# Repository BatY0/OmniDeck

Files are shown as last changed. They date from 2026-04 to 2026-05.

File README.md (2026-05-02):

# OmniDeck: An Asymmetric IoT Puzzle Platform

## Project Summary
OmniDeck is an innovative, asymmetric cooperative IoT hardware platform designed to merge physical puzzles with digital cloud-based mechanics—creating a "Keep Talking and Nobody Explodes" style escape room experience. Acting as a "Dumb Terminal," the physical device utilizes an ESP32 to read environmental and interactive telemetry (spatial orientation, rotational vault-cracking inputs, proximity, temperature, and light intensity) and publishes this data to the Arduino IoT Cloud in real-time via WebSockets. A remote "Hacker" monitors these live feeds on a web dashboard and transmits haptic (vibration) clues and game-stage commands back to the console. The cloud platform functions as the ultimate Game Master, orchestrating a complete Sense-Think-Act cycle where the physical hardware is fully decoupled from the game logic, eventually releasing a mechanical servo-latch upon successful cooperation.

## Components List
Our project exceeds the minimum requirements (2 sensors + OLED + 1 actuator) by utilizing a comprehensive ecosystem of components:
*   **Microcontroller:** ESP32 Development Board (ESP-WROOM-32)
*   **Display:** 0.96" I2C OLED Display (128x64)
*   **Sensor 1:** MPU6050 (Accelerometer/Gyroscope)
*   **Sensor 2:** KY-040 (Rotary Encoder with Push Button)
*   **Sensor 3:** HC-SR04 (Ultrasonic Distance Sensor)
*   **Sensor 4:** DHT11 (Temperature & Humidity Sensor)
*   **Sensor 5:** 4-Pin LDR (Light Dependent Resistor Module)
*   **Actuator 1:** SG90 Micro Servo Motor
*   **Actuator 2:** Vibration Motor Module

## Wiring Table & Diagram

| Component | Component Pin | ESP32 GPIO Pin | Notes |
| :--- | :--- | :--- | :--- |
| **OLED Display** | SDA / SCL | GPIO 21 / GPIO 22 | I2C Bus (3.3V) |
| **MPU6050** | SDA / SCL | GPIO 21 / GPIO 22 | I2C Bus (3.3V) |
| **KY-040 Encoder** | CLK / DT / SW | GPIO 32 / 33 / 25 | Hardware Interrupt (3.3V) |
| **HC-SR04** | TRIG / ECHO | GPIO 5 / GPIO 18 | 5V VIN Powered |
| **DHT11** | DATA (S) | GPIO 4 | 3.3V Powered |
| **LDR Module** | A0 (Analog) | GPIO 34 | Analog Input (3.3V) |
| **SG90 Servo** | SIGNAL (Orange) | GPIO 26 | 5V VIN Powered |
| **Vibration Motor**| IN (Signal) | GPIO 27 | 3.3V Powered |

### Wiring Diagram

<p align="center">
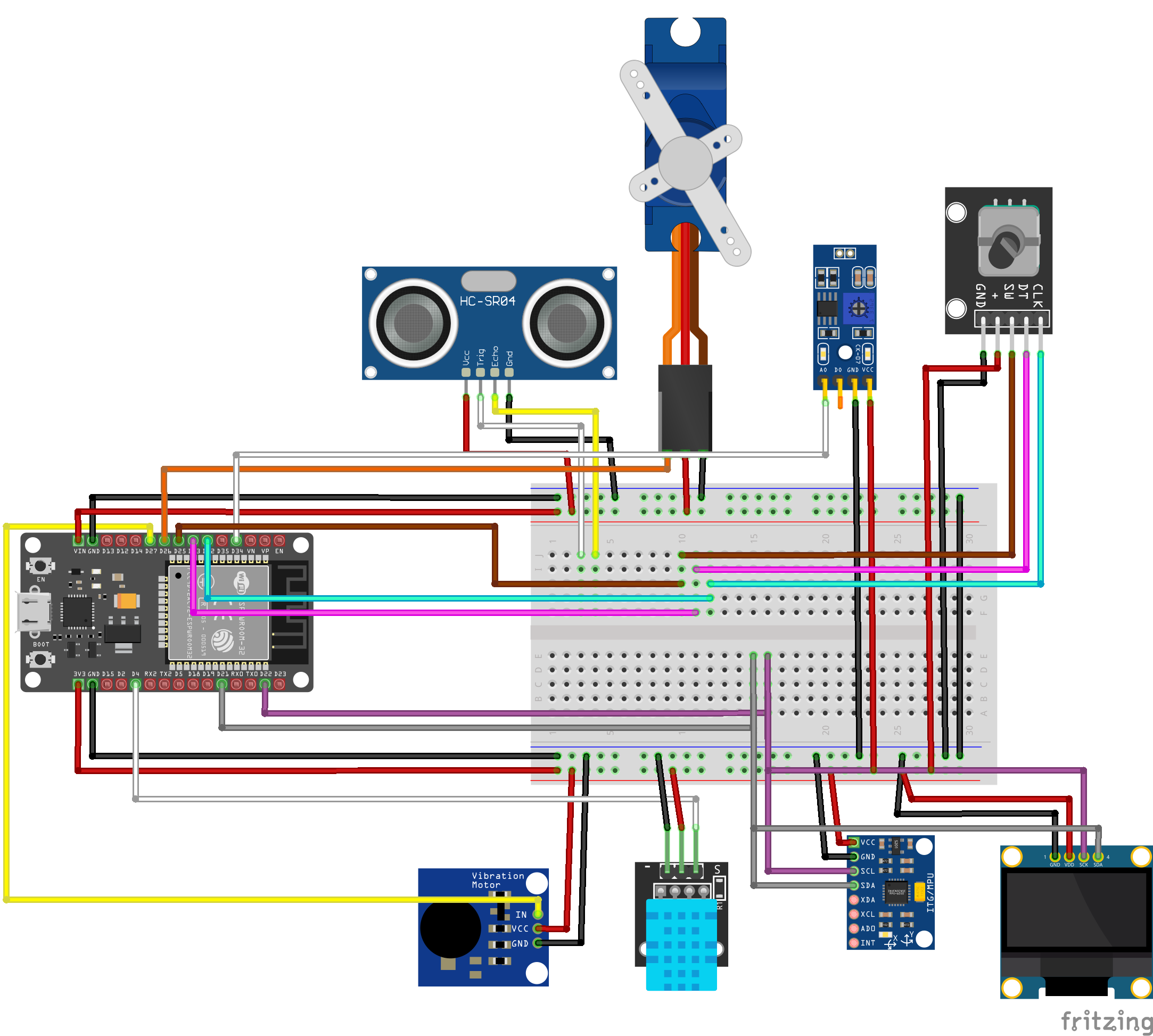
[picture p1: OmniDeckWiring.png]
OmniDeck Wiring Diagram
  
  <br>
  <i>Figure 1: Complete wiring diagram showing ESP32, sensors, and actuators. 5V and 3.3V logic levels are separated via breadboard power rails.</i>
</p>

## Cloud Setup (Arduino IoT Cloud)

*   **Cloud Platform:** Arduino IoT Cloud
*   **Network:** Wi-Fi connected via ESP32.
*   **Cloud Variables (Feeds):**
    *   `dist` (Integer, Read Only, On Change)
    *   `temp` (Floating Point, Read Only, On Change)
    *   `light` (Integer, Read Only, On Change)
    *   `tilt` (Character String, Read Only, On Change)
    *   `dial` (Integer, Read Only, On Change)
    *   `game_log` (Character String, Read Only, On Change)
    *   `hacker_cmd` (Character String, Read & Write, On Change) - *Triggers callback function.*
*   **Dashboard Widgets:**
    *   **Monitoring:** Gauges for Distance & Light, Value widgets for Temp, Tilt, Dial, and a wide Value widget for the `game_log`.
    *   **Control:** String Input / Messenger widget linked to `hacker_cmd` for sending remote terminal commands (e.g., STAGE1, STAGE2, VIB, OPEN).

## How to Run

1.  **Libraries Required:** Install the following via Arduino IDE Library Manager:
    *   `Adafruit GFX Library`
    *   `Adafruit SSD1306`
    *   `Adafruit MPU6050` & `Adafruit Unified Sensor`
    *   `DHT sensor library`
    *   `ESP32Servo`
    *   `ArduinoIoTCloud` & `Arduino_ConnectionHandler`
2.  **Board Settings:** Select **DOIT ESP32 DEVKIT V1** in the Arduino IDE.
3.  **Network Configuration:** In the Arduino Cloud Web Editor, navigate to the `Secret` tab or `arduino_secrets.h` and input your `SECRET_SSID` (Wi-Fi Name) and `SECRET_PASS` (Wi-Fi Password).
4.  **Upload:** Connect the ESP32 via USB and upload the sketch.

## How it Works (Logic & Data Flow)

The system operates on a rapid **Sense-Think-Act** loop synchronized with the cloud via WebSockets:
1.  **Data Upload (Sense & Think):** Every 100ms, the ESP32 reads local hardware (converting MPU vectors to directional strings like "RIGHT", interpreting the LDR light intensity, etc.). The Rotary Encoder uses a hardware interrupt (`IRAM_ATTR`) to guarantee zero-latency turning. Variables are automatically pushed to the Arduino Cloud upon any change.
2.  **Dashboard Control Logic (Act):** The Hacker observes the live sensor data on the dashboard and issues game-progression commands via the `hacker_cmd` terminal. 
    *   When the Hacker sends a command (e.g., `"STAGE1"` or `"VIBLONG"`), the cloud pushes this value to the ESP32.
    *   The `onHackerCmdChange()` callback function is triggered locally on the ESP32, which then alters the game state, updates the OLED prompt zone, or actuates the hardware (moving the SG90 servo to lock/unlock, or pulsing the vibration motor for Haptic Morse Code).
3.  **Local UI:** The OLED is hardcoded to represent 3 functional zones: The Status Bar (Network/Cloud state), the Interaction Zone (Sensor readouts and a dynamic inclinometer ball), and the Prompt Zone (Real-time remote commands).

## Evidence

### Dashboard Screenshots

<p align="center">
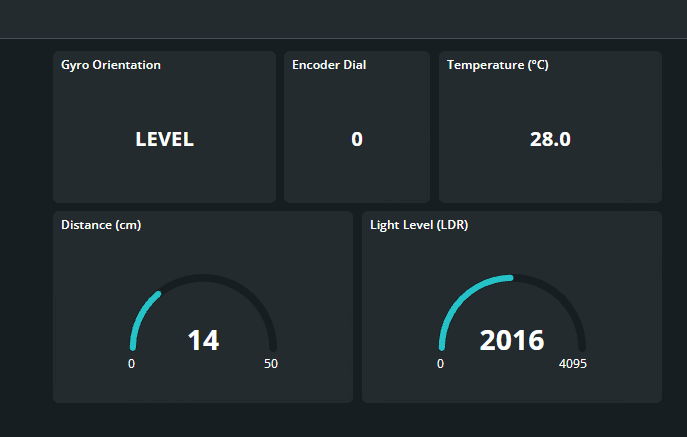
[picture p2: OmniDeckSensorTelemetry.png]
Sensor Telemetry Dashboard
  
  <br>
  <i>Figure 2: "Academic Overview" dashboard displaying real-time telemetry from all 5 sensors to meet project requirements.</i>
</p>

<p align="center">
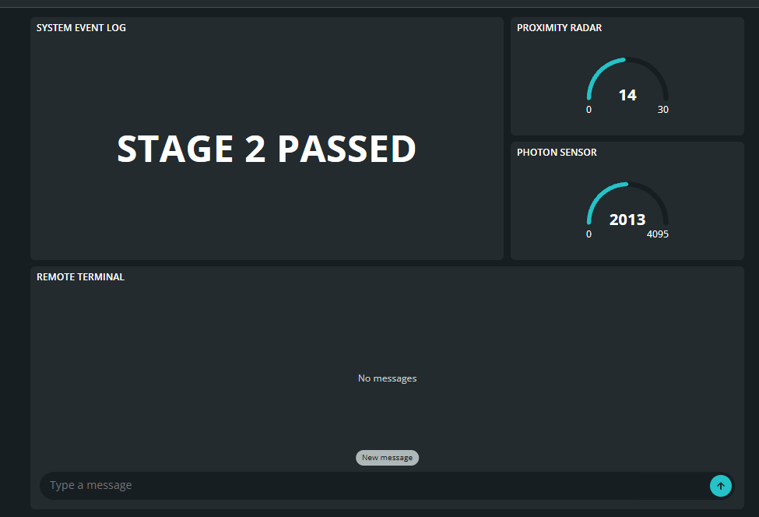
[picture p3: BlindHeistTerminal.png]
Hacker Terminal Dashboard
  
  <br>
  <i>Figure 3: "The Blind Heist" Mission Control terminal. Used by the Hacker to send remote commands (STAGE1, OPEN, VIB) and monitor live game logs.</i>
</p>

### Demonstration
Watch the full functionality and game demo here:
**[▶️ Click here to watch the OmniDeck Demo Video on YouTube/Drive] (#)** 
*(Note: Link will be updated before the presentation).*

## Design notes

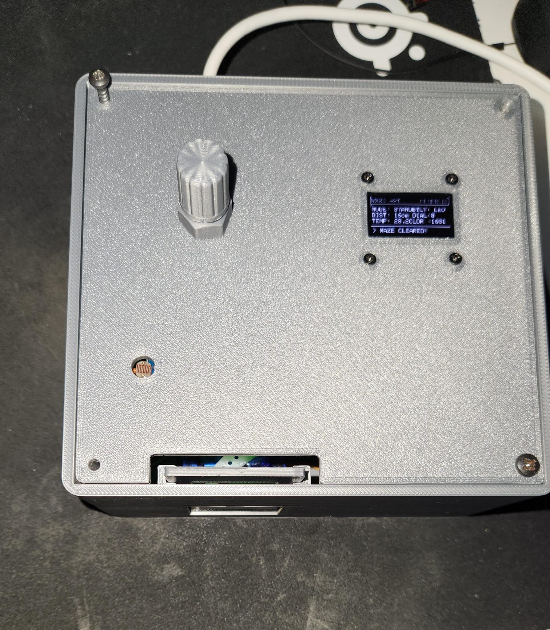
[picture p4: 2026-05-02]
3ModelFilles/ImagesFromPrototypes/V3/WorkingPrototype.jpeg

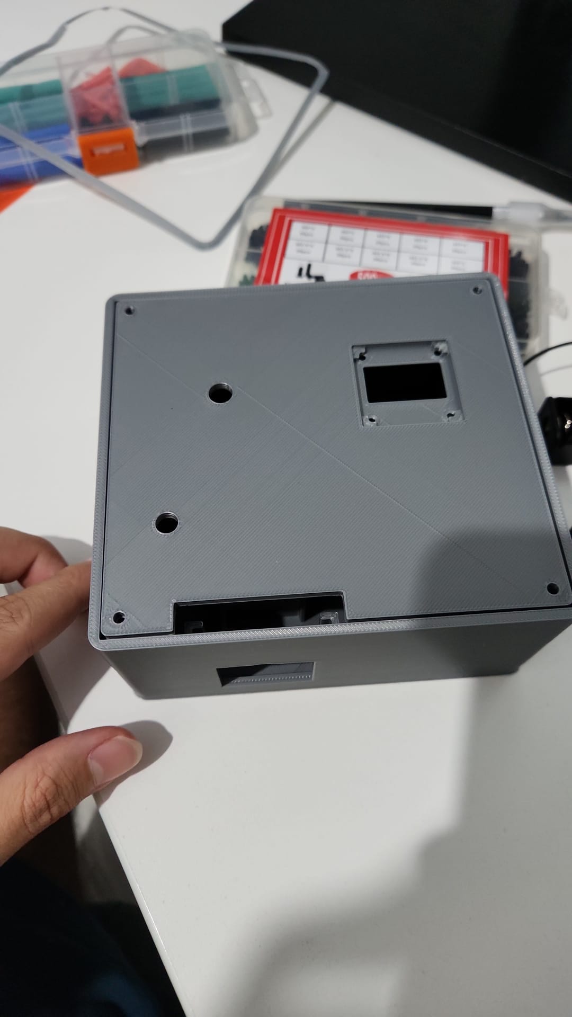
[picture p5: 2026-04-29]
3ModelFilles/ImagesFromPrototypes/V3/WithLidButLidMirrored.jpeg

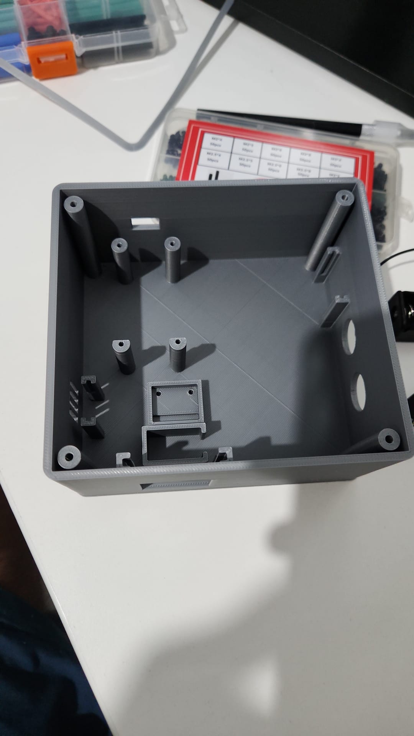
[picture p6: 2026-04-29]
3ModelFilles/ImagesFromPrototypes/V3/Empty.jpeg

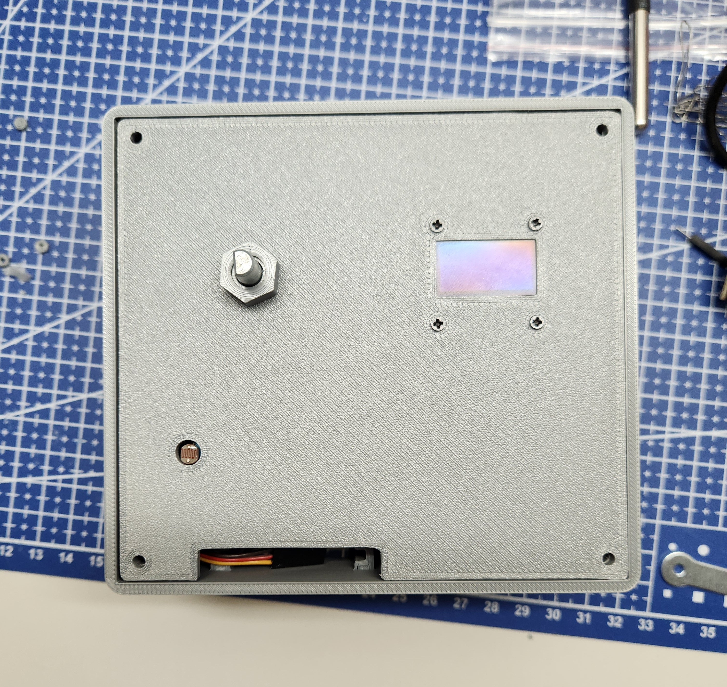
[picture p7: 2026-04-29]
3ModelFilles/ImagesFromPrototypes/V3/Full.jpg

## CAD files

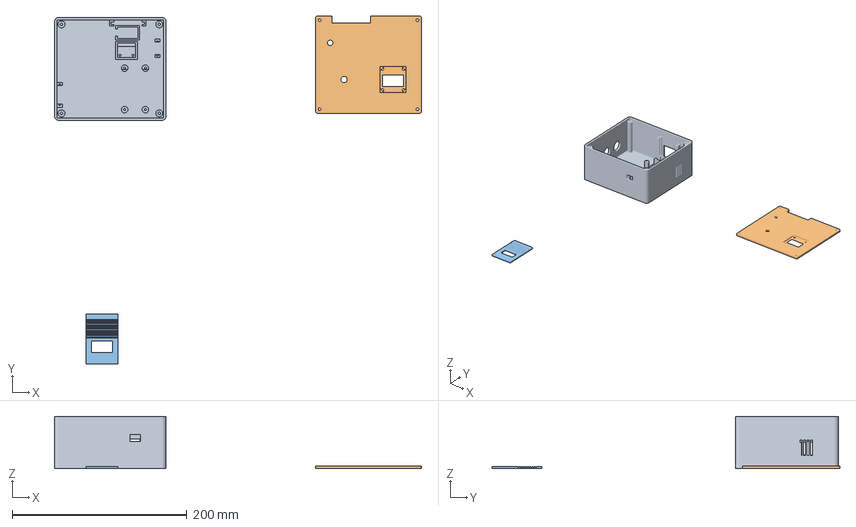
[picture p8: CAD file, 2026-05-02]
3ModelFilles/3DShellandLid.3mf
420.4 x 398.4 x 60.0 mm

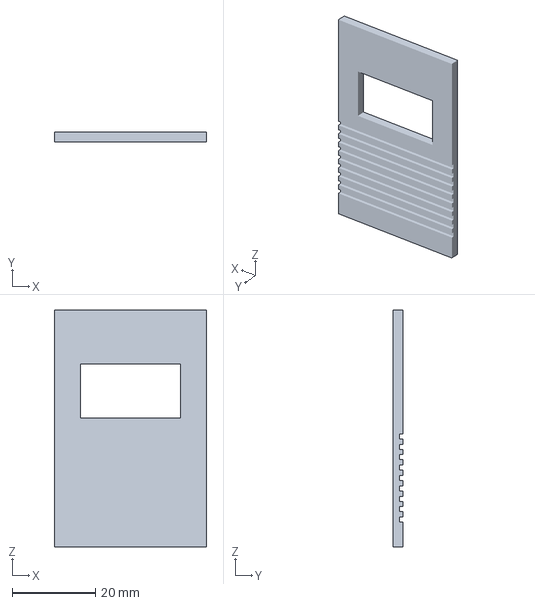
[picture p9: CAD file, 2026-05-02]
3ModelFilles/Lid.3mf
36.6 x 2.40 x 57.0 mm

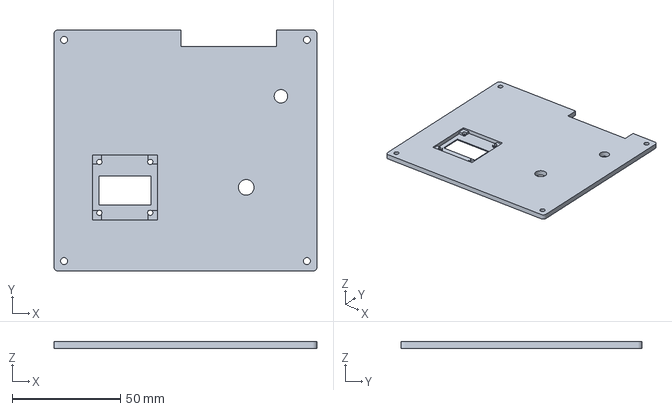
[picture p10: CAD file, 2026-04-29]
3ModelFilles/3DLid.3mf
121.3 x 111.3 x 3.00 mm

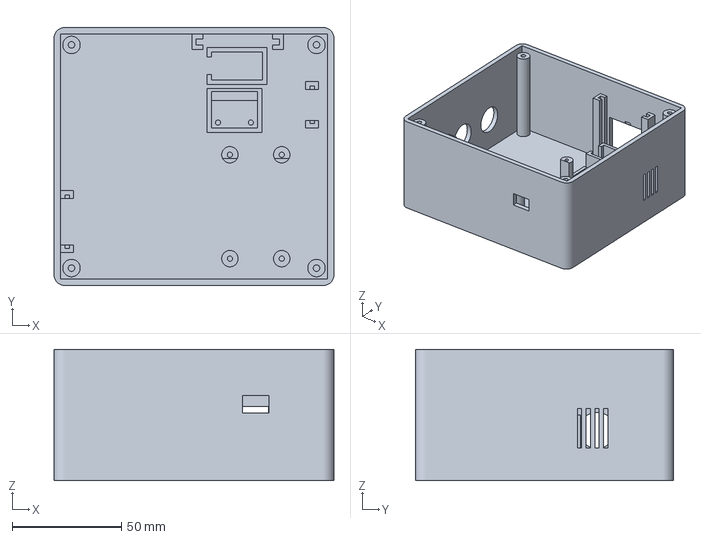
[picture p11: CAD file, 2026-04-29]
3ModelFilles/3DShellV3.3mf
128.0 x 118.0 x 60.0 mm

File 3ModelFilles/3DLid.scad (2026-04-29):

// OmniDeck IoT Console - Yüksek Hassasiyetli Mekanik Tasarım
// Versiyon 24.9.12 - Dış PCB çerçevesi 30.0'a geri alındı, İç köşeler maksimumda.

$fn = 60;

/*[TEKNİK PARAMETRELER - KASA] */
outerWidth = 128;
outerDepth = 118;
baseHeight = 60; 
wallT = 3;
floorT = 3;
tol = 0.6; 
eps = 0.1; 

/*[KULLANICI REFERANS KAPAK (LID) PARAMETRELERİ] */
lidThickness = 3;
lipClearance = 0.35;
lidHoleDiameter = 3.2;

// --- OLED EKRAN (SSD1306) HASSAS GÜNCELLEMELERİ ---
oledWindowWidth = 24.0;   
oledWindowHeight = 13.5;  
oledWindowOffsetY = -1.5; 

oledDepthPcb = 1.0;       
oledDepthClearance = 2.4; 

oledCenterX = 36;
oledCenterY = 42;

encoderHoleDiameter = 7.2;
encoderCenterX = 92;
encoderCenterY = 42;

ldrHoleDiameter = 6.2;
ldrCenterX = 108;
ldrCenterY = 84;

/*[BİLEŞEN ÖLÇÜLERİ VE KOORDİNATLAR] */
hcHoleD = 16.5;
hcSpacing = 26;
hcCenterY = 70; 
hcCenterZ = 23; 

espW = 28.5; 
espD = 51.6; 
espX = 78; 
espY = 12;  
espH = 30;  
espScrewD = 2.4; 

servoX = 70;
servoY = 92; 
servoW = 22.8 + tol;
servoD = 12.2 + tol;
servoArmTopZ = floorT + 32.4; 

mpuX = 70; 
mpuY = 70; 
mpuW = 21.0; 
mpuD = 16.2;

dhtY = 72;

vibX = wallT;
vibY = 15; 

hatchX = 70;
hatchW = 28;
hatchH = 24;
hatchZ = 10; 
latchSlotH = 4.5;
latchSlotZ = servoArmTopZ - latchSlotH; 


/*[YARDIMCI MODÜLLER] */
module box_frame(w, d, h, r) {
    hull() {
        for(x=[r, w-r], y=[r, d-r]) {
            translate([x,y,0]) cylinder(h=h, r=r);
        }
    }
}

/*[1. ANA GÖVDE (SHELL)] */
module main_shell() {
    bridgeZ = hatchZ + hatchH; 
    slotTopZ = latchSlotZ + latchSlotH; 
    railDepth = 7;
    channelGap = 2.8; 
    railH = 45; 
    espOffX = 2.4; 
    dht_W = 16.6; 
    pcb_W = dht_W + 0.6; 
    pcb_T = 2.0; 
    v_W = 23.8; 
    vp_W = v_W + 0.6; 
    vp_T = 2.0; 

    union() {
        difference() {
            box_frame(outerWidth, outerDepth, baseHeight, 5);
            
            translate([wallT, wallT, floorT])
                cube([outerWidth - wallT*2, outerDepth - wallT*2, baseHeight]);

            translate([-eps, hcCenterY - hcSpacing/2, hcCenterZ]) rotate([0,90,0]) cylinder(d=hcHoleD, h=wallT + 2*eps);
            translate([-eps, hcCenterY + hcSpacing/2, hcCenterZ]) rotate([0,90,0]) cylinder(d=hcHoleD, h=wallT + 2*eps);

            translate([hatchX, outerDepth-wallT-eps, hatchZ]) cube([hatchW, wallT + 2*eps, hatchH]);
            
            if (slotTopZ > bridgeZ) {
                translate([hatchX + 11.8, outerDepth-wallT-eps, bridgeZ + 0.2]) 
                    cube([4.4, wallT + 2*eps, slotTopZ - (bridgeZ + 0.2)]);
            }

            for(i =[0:3]) {
                translate([outerWidth-wallT-eps, dhtY + 2 + (i*4.0), 15]) cube([wallT + 2*eps, 2.0, 18]);
            }
            
            translate([espX + espW/2 - 6, -eps, floorT + espH - 2])
                cube([12, wallT + 2*eps, 8]);
        }

        for(x =[8, outerWidth-8], y =[8, outerDepth-8]) {
            translate([x, y, floorT])
            difference() {
                cylinder(h = baseHeight - floorT - lidThickness, d = 8);
                translate([0,0,-eps]) cylinder(h = baseHeight, d = 3.0); 
            }
        }

        translate([68 - 5, outerDepth - wallT - railDepth, floorT]) {
            difference() {
                cube([5, railDepth, railH]);
                translate([5 - 3, 2, -eps]) cube([4, channelGap, railH + 2*eps]);
            }
        }
        
        translate([100, outerDepth - wallT - railDepth, floorT]) {
            difference() {
                cube([5, railDepth, railH]);
                translate([-1, 2, -eps]) cube([4, channelGap, railH + 2*eps]);
            }
        }
        
        for(ix =[espOffX, espW - espOffX]) {
            translate([espX + ix, espY + 3.8 - 3.5, floorT])
            difference() {
                cylinder(d=7.5, h=espH);
                translate([0,0,espH-15]) cylinder(d=espScrewD, h=16); 
            }
            
            translate([espX + ix, espY + espD - 3.8, floorT])
            difference() {
                cylinder(d=7.5, h=espH);
                translate([0,0,espH-15]) cylinder(d=espScrewD, h=16); 
                translate([-5, -11.8, espH - 12]) cube([10, 10, 13]);
            }
        }
        
        translate([servoX, servoY, floorT])
            difference() {
                cube([servoW + 4, servoD + 4, 16]); 
                translate([2, 2, -eps]) cube([servoW, servoD, 20]); 
                translate([-eps, (servoD + 4)/2 - 4, -eps]) cube([10, 8, 20]);
            }

        translate([mpuX, mpuY, floorT])
            difference() {
                cube([mpuW + 4, mpuD + 4, 8]); 
                translate([2, 2, 3.5]) cube([mpuW, mpuD, 10]); 
                translate([2, mpuD - 1.5, 1.5]) cube([mpuW, 4, 10]);
                for(mx =[5, 20]) { translate([mx, 4.5, 0]) cylinder(d=2.4, h=10); }
            }

        translate([outerWidth - wallT - 10, dhtY, floorT]) {
            difference() {
                cube([pcb_T + 4, pcb_W + 4, 27]);
                translate([2, 2, 13]) cube([pcb_T, pcb_W, 15]);
                translate([-eps, 3.5, -eps]) cube([10, pcb_W - 3, 30]);
            }
        }

        translate([vibX, vibY, floorT]) {
            difference() {
                cube([vp_T + 4, vp_W + 4, 28]);
                translate([2, 2, 8]) cube([vp_T, vp_W, 25]);
                translate([-eps, 3.5, -eps]) cube([10, vp_W - 3, 30]);
            }
        }
    }
}

/*[2. KAPAK (LID) MODÜLÜ] */
/*[2. KAPAK (LID) MODÜLÜ] */
/*[2. KAPAK (LID) MODÜLÜ] */
/*[2. KAPAK (LID) MODÜLÜ] */
module shell_lid() {
    lidW = outerWidth - 2*wallT - lipClearance*2;
    lidD = outerDepth - 2*wallT - lipClearance*2;
    lidR = 5 - wallT; 
    oledPitch = 23.5; 
    railDepth = 7;
    doorSlotX = 62; 
    doorSlotW = 44; 
    doorSlotY = outerDepth - wallT - railDepth - 1; 
    doorSlotD = railDepth + 2;
    oledPcbPocket = 30.0; 

    difference() {
        translate([wallT + lipClearance, wallT + lipClearance, 0])
            box_frame(lidW, lidD, lidThickness, lidR);
        
        for(x=[8, outerWidth-8], y=[8, outerDepth-8]) {
            translate([x, y, -eps]) 
                cylinder(h=lidThickness + 2*eps, d=lidHoleDiameter);
        }
        
        // OLED Penceresi
        translate([oledCenterX - oledWindowWidth/2, oledCenterY - oledWindowHeight/2 + oledWindowOffsetY, -eps])
            cube([oledWindowWidth, oledWindowHeight, lidThickness + 2*eps]);
            
        // OLED Sığ Raf (PCB Dış Çerçevesi 30.0)
        translate([oledCenterX - oledPcbPocket/2, oledCenterY - oledPcbPocket/2, lidThickness - oledDepthPcb])
            cube([oledPcbPocket, oledPcbPocket, oledDepthPcb + eps]);
            
        // --- KUSURSUZ İÇ KANALLAR (VİDA KALKANLARI SİLİNDİ) ---
        // Slicer hatasını önlemek ve maksimum boşluk için kanallar 21.5mm'ye çıkarıldı.
        // Bu genişlik vida delikleriyle temiz bir şekilde kesişir.
        translate([0, 0, lidThickness - oledDepthClearance]) {
            union() {
                // Dikey Kanal (Lehimler ve Bant için) - Genişlik 21.5
                translate([oledCenterX - 21.5/2, oledCenterY - 30/2, 0])
                    cube([21.5, 30, oledDepthClearance + eps]);
                // Yatay Kanal (Cam esnemesi için) - Yükseklik 21.5
                translate([oledCenterX - 30/2, oledCenterY - 21.5/2, 0])
                    cube([30, 21.5, oledDepthClearance + eps]);
            }
        }
            
        // OLED Vidaları (2.4mm Delikler)
        for(hx = [-1, 1], hy =[-1, 1]) {
            translate([oledCenterX + (hx * oledPitch/2), oledCenterY + (hy * oledPitch/2), -eps])
            cylinder(h=lidThickness + 2*eps, d=2.4); 
        }
            
        // Rotary Encoder Deliği
        translate([encoderCenterX, encoderCenterY, -eps])
            cylinder(h=lidThickness + 2*eps, d=encoderHoleDiameter);
            
        // LDR Sensörü Deliği
        translate([ldrCenterX, ldrCenterY, -eps])
            cylinder(h=lidThickness + 2*eps, d=ldrHoleDiameter);
            
        // Kapı Boşluğu (Sürgü Çıkışı)
        translate([doorSlotX, doorSlotY, -eps])
            cube([doorSlotW, doorSlotD, lidThickness + 2*eps]);
    }
}

// --- ÇİZİM ÇAĞRILARI ---
// Hangi parçayı dışa aktarmak istiyorsan onun başındaki '//' işaretini kaldır
//main_shell();
shell_lid();

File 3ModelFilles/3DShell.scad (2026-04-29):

// OmniDeck IoT Console - Yüksek Hassasiyetli Mekanik Tasarım
// Versiyon 24.8 - ESP32 ve MPU Yerleri Kullanıcı İsteğine Göre Sabitlendi
// ESP32: 51.6mm x 28.5mm (78,12) | MPU: (70,70) | Kapı: (70)

$fn = 60;

/* [TEKNİK PARAMETRELER - KASA] */
outerWidth = 128;
outerDepth = 118;
baseHeight = 45;
wallT = 3;
floorT = 3;
tol = 0.6; // Baskı toleransı
eps = 0.1; // Manifold hatalarını önlemek için küçük ek pay

/* [BİLEŞEN ÖLÇÜLERİ VE KOORDİNATLAR] */
// HC-SR04 (Sol duvar)
hcHoleD = 16.5;
hcSpacing = 26;
hcCenterY = 70; 
hcCenterZ = 23;

// ESP32 DevKitV1 (Hassas Ölçü: 51.6 x 28.5)
// Kullanıcının istediği sabit konuma geri getirildi
espW = 28.5; 
espD = 51.6; 
espX = 78; 
espY = 12;  
espH = 35; 
espScrewD = 2.4; 

// SG90 Servo Yatağı (Sağ Üst)
// Hatch ile hizalı (X=70)
servoX = 70;
servoY = 92; 
servoW = 22.8 + tol;
servoD = 12.2 + tol;
servoArmTopZ = floorT + 32.4; 

// MPU-6050 Yatağı (Kullanıcının İstediği Sabit Konum)
mpuX = 70; 
mpuY = 70; 
mpuW = 21.0; 
mpuD = 16.2;

// DHT11 Modülü (Dikey Duvar Montajı - Sağ taraf)
dhtPCB_W = 16.5 + tol;
dhtPCB_T = 1.6 + tol;
dhtSensor_T = 7.2 + tol; 
dhtY = 72;

// Titreşim Motoru Modülü (Dikey Duvar Montajı - Sol taraf)
vibPCB_W = 16.0 + tol; 
vibPCB_T = 1.6 + tol; 
vibX = wallT;
vibY = 20;

// Kapı ve Kilit (Arka Duvar - Servo ile tam hizalı)
hatchX = 70;
hatchW = 28;
hatchH = 24;
hatchZ = 10; 
latchSlotH = 4.5;
latchSlotZ = servoArmTopZ - latchSlotH; 

/* [Modüller] */

module box_frame(w, d, h, r) {
    hull() {
        for(x=[r, w-r], y=[r, d-r]) {
            translate([x,y,0]) cylinder(h=h, r=r);
        }
    }
}

module main_shell() {
    union() {
        difference() {
            // 1. Ana Gövde
            box_frame(outerWidth, outerDepth, baseHeight, 5);
            
            // 2. İç Boşluk
            translate([wallT, wallT, floorT])
                cube([outerWidth - wallT*2, outerDepth - wallT*2, baseHeight]);

            // 3. SOL YAN: Ultrasonik Delikler
            translate([-eps, hcCenterY - hcSpacing/2, hcCenterZ]) rotate([0,90,0]) cylinder(d=hcHoleD, h=wallT + 2*eps);
            translate([-eps, hcCenterY + hcSpacing/2, hcCenterZ]) rotate([0,90,0]) cylinder(d=hcHoleD, h=wallT + 2*eps);

            // 4. ARKA: Kapı Açıklığı
            translate([hatchX, outerDepth-wallT-eps, hatchZ]) cube([hatchW, wallT + 2*eps, hatchH]);
            
            // 5. ARKA: Kilit Yuvası
            translate([hatchX + 11.8, outerDepth-wallT-eps, latchSlotZ]) 
                cube([4.4, wallT + 2*eps, latchSlotH]);

            // 6. SAĞ YAN: DHT11 için havalandırma slotları
            for(i = [0:3]) {
                translate([outerWidth-wallT-eps, dhtY + 2 + (i*4.0), 15]) cube([wallT + 2*eps, 2.0, 18]);
            }
            
            // 7. ÖN DUVAR: ESP32 USB Girişi
            translate([espX + espW/2 - 6, -eps, floorT + espH - 5])
                cube([12, wallT + 2*eps, 8]);
        }

        // 8. KAPAK VİDA SÜTUNLARI (M3)
        for(x = [8, outerWidth-8], y = [8, outerDepth-8]) {
            translate([x, y, floorT])
            difference() {
                cylinder(h = baseHeight - floorT, d = 8);
                translate([0,0,-eps]) cylinder(h = baseHeight + 2*eps, d = 3.0); 
            }
        }

        // 9. SÜRGÜ RAYLARI (TAM "U" FORMU - BİRBİRİNE BAKAN SLOTLAR)
        railDepth = 7;
        channelGap = 2.8; 
        railH = hatchZ + hatchH + 10;
        
        // Kapı kenarları X=68 ve X=100 koordinatlarına denk gelir.
        
        // Sol Ray (Kanal sağa bakar)
        translate([68 - 5, outerDepth - wallT - railDepth, floorT]) {
            difference() {
                cube([5, railDepth, railH]);
                translate([5 - 3, 2, -eps]) 
                    cube([4, channelGap, railH + 2*eps]);
            }
        }
        
        // Sağ Ray (Kanal sola bakar)
        translate([100, outerDepth - wallT - railDepth, floorT]) {
            difference() {
                cube([5, railDepth, railH]);
                translate([-1, 2, -eps]) 
                    cube([4, channelGap, railH + 2*eps]);
            }
        }
        
        // 10. ESP32 SÜTUNLARI (Vidalama Delikli - 51.6x28.5)
        for(ix = [0, espW], iy = [0, espD]) {
            translate([espX + ix, espY + iy, floorT])
            difference() {
                cylinder(d=8, h=espH);
                translate([0,0,espH-15]) cylinder(d=espScrewD, h=16); 
            }
        }
        
        // 11. SERVO YATAĞI (Kablo Çıkışı Tam Merkezde)
        translate([servoX, servoY, floorT])
            difference() {
                cube([servoW + 4, servoD + 4, 6]); 
                translate([2, 2, -eps]) cube([servoW, servoD, 10]); 
                translate([-eps, (servoD + 4)/2 - 4, 1.5]) cube([10, 8, 10]);
            }

        // 12. MPU-6050 YATAĞI (Restored to 70,70)
        translate([mpuX, mpuY, floorT])
            difference() {
                cube([mpuW + 4, mpuD + 4, 6]); 
                translate([2, 2, 1.5]) cube([mpuW, mpuD, 10]); 
                for(mx = [4, mpuW]) {
                    translate([mx, 2, 0]) cylinder(d=4, h=6);
                }
            }
        for(mx = [4, mpuW]) {
             translate([mpuX+mx, mpuY+2, floorT-eps]) 
                cylinder(d=2.4, h=10);
        }

        // 13. DHT11 DİKEY YUVA
        translate([outerWidth - wallT - dhtSensor_T - dhtPCB_T - 2, dhtY, floorT]) {
            difference() {
                union() {
                    cube([dhtPCB_T + 4, 2, 20]); 
                    translate([0, dhtPCB_W + 2, 0]) cube([dhtPCB_T + 4, 2, 20]); 
                    cube([dhtPCB_T + 4, dhtPCB_W + 4, 2]); 
                }
                translate([2, 2, -eps]) cube([dhtPCB_T, dhtPCB_W, 25]);
                translate([dhtPCB_T+2, dhtPCB_W/2+2, 10]) rotate([0,90,0]) cylinder(d=2.4, h=10);
            }
        }

        // 14. TİTREŞİM MOTORU DİKEY YUVA
        translate([vibX, vibY, floorT]) {
            difference() {
                union() {
                    cube([6, 2, 15]); 
                    translate([0, vibPCB_W+2, 0]) cube([6, 2, 15]); 
                    cube([2, vibPCB_W+4, 2]);
                }
                translate([2, 2, -eps]) cube([vibPCB_T, vibPCB_W, 20]);
            }
        }
            
        // Breadboard Görsel Rehberi
        %translate([10, 15, floorT]) color("pink", 0.3) cube([54, 82, 9]);
    }
}

// Render
main_shell();

// Aksesuar: Kapı ve Kilit Kolu
translate([outerWidth + 20, 0, 0]) {
    union() {
        difference() {
            cube([32, 30, 2]); 
            for(i=[0:5]) translate([10, 5 + i*3, 1.5]) cube([12, 1.5, 1]);
        }
        translate([16 - 2.1, 30, 0]) cube([4.2, 3.5, 2]);
    }
    translate([45, 0, 0])
    difference() {
        cube([4.4, 18, 2.2]);
        translate([1.2, 2.5, -eps]) cube([2, 7.5, 5]);
    }
}

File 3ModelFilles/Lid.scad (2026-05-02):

// OmniDeck IoT Console - Gömme Sürgülü Kapı (Sliding Door)
// Versiyon 2.3 - Tırtıklar Aşağıda (Görünür Bölgede), Servo Penceresi Yukarıda

$fn = 60;
eps = 0.1;

module final_fixed_door() {
    doorW = 36.6; 
    doorT = 2.4;  
    doorH = 57;   

    union() {
        difference() {
            // 1. ANA PANEL
            // Baskı sırasında arka (düz) yüzeyini tablaya yapıştırın.
            cube([doorW, doorT, doorH]);
            
            // 2. KİLİT PENCERESİ (Yukarı taşındı)
            // Servonun beyaz kolu fotoğrafta yukarıda görünüyor.
            // Bu pencere artık 32mm'den başlayıp 45mm'ye kadar uzanıyor.
            translate([doorW/2 - 12, -eps, 31]) 
                cube([24, doorT + 2*eps, 13]); 

            // 3. DIŞ YÜZEY SÜRTÜNME KANALLARI (Aşağı indirildi)
            // Kasanın dış deliğinden bakıldığında tam parmak ucuna gelecek yer.
            // Alt kısımdan (6mm'den) başlayarak parmak kavrama alanı oluşturur.
            for(i = [0 : 8]) {
                translate([-eps, doorT - 0.8, 6 + (i * 2.5)])
                    cube([doorW + 2*eps, 1.2, 1.2]);
            }
        }
    }
}

// --- ÇİZİM ÇAĞRILARI ---
final_fixed_door();

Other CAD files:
3ModelFilles/3DShellv2.scad

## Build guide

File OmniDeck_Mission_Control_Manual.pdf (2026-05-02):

# [CLASSIFIED DOCUMENT] - TOP SECRET

DATE: 07/05/2026

SUBJECT: OPERATION: THE BLIND HEIST

CLEARANCE: LEVEL 5 / MISSION CONTROL ONLY

## >> MISSION OVERVIEW

ROLE: MISSION CONTROL (HACKER)

OBJECTIVE: Guide the Field Operative to bypass the OmniDeck security system.

STATUS: The Operative is blind to the solution. You are their only eyes.

## >> COMMUNICATION PROTOCOL: HAPTIC PULSES

CRITICAL: You cannot speak the passwords aloud! You must use the REMOTE TERMINAL to send HAPTIC (Vibration) pulses to the Operative's box. The Operative has no code sheet; they must COUNT your pulses.

### TERMINAL COMMANDS:

- For numbers 1 to 9: Type VIB followed by the number.
- Example: For the number 4, type VIB4. The box will auto-pulse 4 times.
- For number 0: Type VIBLONG.
- Effect: The box will emit one heavy, long pulse.
EXECUTION STRATEGY:
1. Send the first digit.
2. Wait for the Operative to turn the dial and push the button.
3. Send the second digit, and so on.

## >> STAGE 1: THERMAL CRYPTOGRAPHY

INITIALIZATION: Type STAGE1 in Terminal.

MECHANISM: The vault generates a dynamic 3-digit passcode based on the Operative's local room temperature.

### YOUR TASK:

1. Request Data: Ask the Operative: "Read me the TEMP value from your OLED screen!" (e.g., 28.4 C).
2. Algorithm Calculation: Ignore the decimals. Use this formula:
- Digit 1: Tens digit of Temp (e.g., 2)
- Digit 2: Ones digit of Temp (e.g., 8)
- Digit 3: (Digit 1 + Digit 2)
■ (Note: If the sum is > 9, use the last digit. E.g., 2+8=10, result is 0)
- RESULTING CODE: 2 - 8 - 0
3. Transmission: Send the code using the HAPTIC PULSES method.
4. Confirmation: Wait for "STAGE 1 PASSED" in the SYSTEM EVENT LOG.

## >> STAGE 2: THE INVISIBLE MAZE

INITIALIZATION: Type STAGE2 in Terminal.

MECHANISM: The vault’s gyro is linked to a 5x5 digital grid. The Operative is blind to the walls.

### NAVIGATION RULES:

- LEVELING: The Operative MUST return the box to the flat LEVEL position after EVERY single move. (Sequence: Tilt -> Level -> Tilt -> Level).
- COORDINATES:
- Start Point (S): X:2, Y:4
- Exit Point (E): X:2, Y:0

### THE MAZE MAP (MISSION CONTROL EYES ONLY):

Coordinate | X:0 | X:1 | X:2 | X:3 | X:4

Y:0

Y:1

Y:2

Y:3

Y:4

Legend:

- W: Wall (Red)
- O: Open (Blue)
- S: Start Position
- E: Exit (Green)

RADAR PROTOCOL: * Command the Operative to tilt ONE step at a time (Left, Right, Front, Back).
- Monitor LOG: "Okay, you are at X1 Y4, path is clear, move Front!"
- WARNING: If they hit a Wall (W), the box vibrates violently and resets to START!

## >> STAGE 3: BIOMETRIC OVERRIDE

INITIALIZATION: Type STAGE3 in Terminal.

MECHANISM: Physical presence calibration. The Operative does not know the target values.

### YOUR TASK:

1. Command: "Cover the light sensor and hold your hand in front of the radar!"
2. Monitor Dashboard Targets:
- PHOTON SENSOR: Must drop below 1500.
- PROXIMITY RADAR: Must stay between 8 cm and 14 cm.
3. Guidance: "Move your hand closer... closer... hold it! Don't move!"
4. Sync: Tell them to watch the 5-second countdown. If they shake, "SYNC LOST" will trigger.

## >> EMERGENCY SYSTEM OVERRIDES

Use these commands ONLY if sensors fail or the Operative panics:
- OPEN - Force bypass the servo lock.
- CLOSE - Hard reset and lock the entire vault.
[END OF DOCUMENT]

SIGNAL ENCRYPTED // TERMINATE SESSION

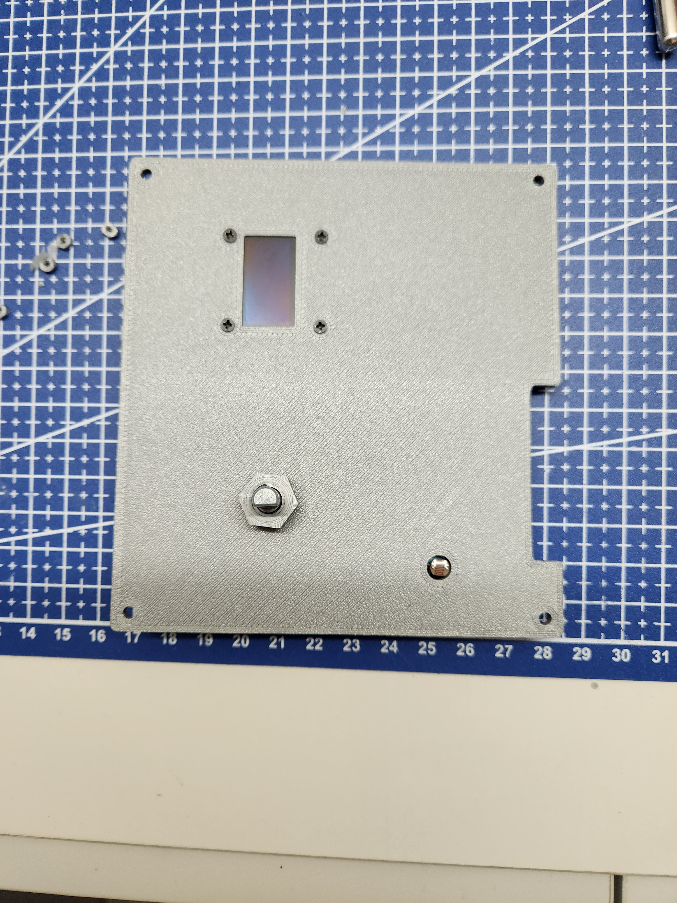
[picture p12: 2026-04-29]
3ModelFilles/ImagesFromPrototypes/V3/LidAssembledFront.jpg

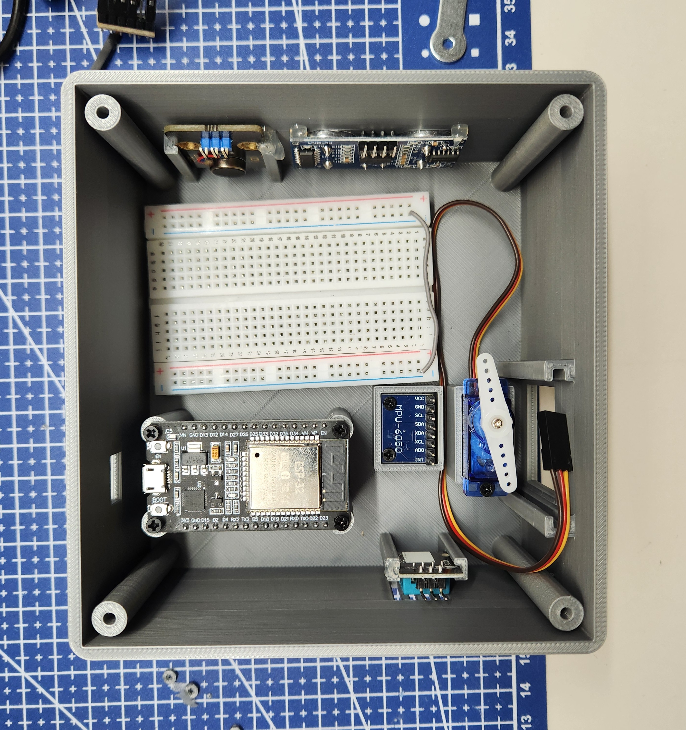
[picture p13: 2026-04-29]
3ModelFilles/ImagesFromPrototypes/V3/ShellAssembled2.jpg

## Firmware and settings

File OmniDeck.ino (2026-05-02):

/*
  Project: OmniDeck - An Asymmetric IoT Puzzle Platform
  Description: ESP32 IoT Code for Sensors, Actuators, OLED UI, and Arduino Cloud Sync.
  Game Mode: Operation "The Blind Heist"
*/

#include "thingProperties.h"
#include <Wire.h>
#include <Adafruit_GFX.h>
#include <Adafruit_SSD1306.h>
#include <Adafruit_MPU6050.h>
#include <Adafruit_Sensor.h>
#include <DHT.h>
#include <ESP32Servo.h>

// --- Pin Definitions ---
#define DHTPIN 4
#define DHTTYPE DHT11
#define ENC_CLK 32
#define ENC_DT 33
#define ENC_SW 25
#define ULTRA_TRIG 5
#define ULTRA_ECHO 18
#define LDR_PIN 34
#define SERVO_PIN 26
#define VIB_PIN 27

// --- Objects ---
Adafruit_SSD1306 display(128, 64, &Wire, -1);
Adafruit_MPU6050 mpu;
DHT dht11(DHTPIN, DHTTYPE);
Servo kilitServo;

// --- Local Variables ---
String promptMsg = "AWAITING MISSION";
String deviceMode = "IDLE"; 
int currentStage = 0; 
unsigned long lastSensorRead = 0;

// Encoder Interrupt Variable
volatile int localDial = 0; 

// Stage 1 Variables
int targetPass[3] = {0, 0, 0};
int enteredPass[3] = {0, 0, 0};
int passIndex = 0;

// Stage 2 Variables (5x5 Maze)
int mazeX = 2; int mazeY = 4; // Start Point (S)
bool mazeReady = false; 
const int mazeMap[5][5] = {
  {1, 1, 1, 1, 2}, // Y:0 (2 = Exit)
  {0, 0, 0, 1, 0}, // Y:1 (0 = Path)
  {0, 1, 0, 0, 0}, // Y:2 (1 = Wall)
  {0, 0, 1, 1, 0}, // Y:3
  {1, 0, 0, 1, 0}  // Y:4 (Start X:2, Y:4)
};

// Stage 3 Variables
unsigned long countdownStart = 0;

// ==========================================
// HARDWARE INTERRUPT (ENCODER)
// ==========================================
void IRAM_ATTR encoderISR() {
  static unsigned long lastInterruptTime = 0;
  unsigned long interruptTime = millis();
  
  if (interruptTime - lastInterruptTime > 5) { // Debounce
    if (digitalRead(ENC_DT) == LOW) {
      localDial--; // Clockwise
    } else {
      localDial++; // Counter-Clockwise
    }
    
    // --- DIAL WRAPAROUND (0 - 9) ---
    if (localDial > 9) localDial = 0;
    else if (localDial < 0) localDial = 9;
    
    lastInterruptTime = interruptTime;
  }
}

void setup() {
  Serial.begin(115200);
  delay(1500); 

  // Init Pins
  pinMode(VIB_PIN, OUTPUT);
  pinMode(ENC_CLK, INPUT_PULLUP);
  pinMode(ENC_DT, INPUT_PULLUP);
  pinMode(ENC_SW, INPUT_PULLUP);
  pinMode(ULTRA_TRIG, OUTPUT);
  pinMode(ULTRA_ECHO, INPUT);

  // Attach Interrupt
  attachInterrupt(digitalPinToInterrupt(ENC_CLK), encoderISR, FALLING);

  // Init Servo (Safe Lock Position)
  kilitServo.write(40);
  delay(50);
  ESP32PWM::allocateTimer(0);
  kilitServo.setPeriodHertz(50);
  kilitServo.attach(SERVO_PIN, 500, 2400);

  // Init Display & Sensors
  if(!display.begin(SSD1306_SWITCHCAPVCC, 0x3C)) Serial.println("OLED ERROR");
  display.clearDisplay(); display.display();
  mpu.begin();
  dht11.begin();

  // Init Arduino Cloud
  initProperties();
  ArduinoCloud.begin(ArduinoIoTPreferredConnection);
  setDebugMessageLevel(2);
  ArduinoCloud.printDebugInfo();

  hacker_cmd = "IDLE";
  game_log = "SYSTEM ONLINE";
}

void loop() {
  ArduinoCloud.update(); 

  // Read sensors and update logic every 100ms
  if (millis() - lastSensorRead > 100) {
    readSensors();
    runGameLogic();
    updateUI();
    lastSensorRead = millis();
  }
}

// ==========================================
// 1. SENSOR READING & CLOUD SYNC
// ==========================================
void readSensors() {
  // MPU6050
  sensors_event_t a, g, tempEvent;
  mpu.getEvent(&a, &g, &tempEvent);
  float ax = -a.acceleration.y; 
  float ay = a.acceleration.x;

  if (ax > 4) tilt = "RIGHT";
  else if (ax < -4) tilt = "LEFT";
  else if (ay > 4) tilt = "BACK";
  else if (ay < -4) tilt = "FRONT";
  else tilt = "LEVEL";

  // Ultrasonic
  digitalWrite(ULTRA_TRIG, LOW); delayMicroseconds(2);
  digitalWrite(ULTRA_TRIG, HIGH); delayMicroseconds(10);
  digitalWrite(ULTRA_TRIG, LOW);
  dist = pulseIn(ULTRA_ECHO, HIGH) * 0.034 / 2;

  // LDR and DHT
  light = 4095 - analogRead(LDR_PIN);
  temp = dht11.readTemperature();

  // Sync Encoder
  dial = localDial; 
}

// ==========================================
// 2. LOCAL GAME LOGIC
// ==========================================
void runGameLogic() {
  // STAGE 1: PASSCODE ENTRY
  if (currentStage == 1) {
    if (digitalRead(ENC_SW) == LOW) { 
      enteredPass[passIndex] = dial;
      passIndex++;
      triggerVib(100); 
      delay(300); 
      
      if (passIndex == 3) {
        if (enteredPass[0] == targetPass[0] && enteredPass[1] == targetPass[1] && enteredPass[2] == targetPass[2]) {
          promptMsg = "CODE ACCEPTED!";
          game_log = "STAGE 1 PASSED";
          deviceMode = "STANDBY";
          currentStage = 0; 
        } else {
          promptMsg = "WRONG CODE!";
          game_log = "STAGE 1 FAILED";
          passIndex = 0;
          for(int i=0; i<3; i++){ triggerVib(200); delay(150); }
        }
      } else {
        promptMsg = "ENTER DIGIT " + String(passIndex + 1);
      }
    }
  }

  // STAGE 2: INVISIBLE MAZE
  else if (currentStage == 2) {
    if (tilt == "LEVEL") {
      mazeReady = true; 
    } 
    else if (mazeReady) { 
      int nextX = mazeX;
      int nextY = mazeY;

      if (tilt == "RIGHT") nextX++;
      else if (tilt == "LEFT") nextX--;
      else if (tilt == "FRONT") nextY--;
      else if (tilt == "BACK") nextY++;

      mazeReady = false; 

      if (nextX < 0 || nextX > 4 || nextY < 0 || nextY > 4) {
        triggerVib(500); 
        promptMsg = "OUT OF BOUNDS! RESET"; 
        mazeX = 2; mazeY = 4; 
      } 
      else {
        int cell = mazeMap[nextY][nextX];
        
        if (cell == 1) { // Wall
          triggerVib(500); 
          promptMsg = "IMPACT! RESETTING"; 
          mazeX = 2; mazeY = 4; 
        } 
        else if (cell == 2) { // Exit
          promptMsg = "MAZE CLEARED!"; 
          game_log = "STAGE 2 PASSED"; 
          deviceMode = "STANDBY";
          currentStage = 0;
        } 
        else { // Path
          mazeX = nextX;
          mazeY = nextY;
          triggerVib(50); 
          promptMsg = "POS: X" + String(mazeX) + " Y" + String(mazeY);
          game_log = "OPERATOR AT X" + String(mazeX) + " Y" + String(mazeY);
        }
      }
    }
  }

  // STAGE 3: BIOMETRIC SYNC
  else if (currentStage == 3) {
    if (light < 1500 && dist >= 8 && dist <= 14) {
      if (countdownStart == 0) countdownStart = millis();
      int remain = 5 - ((millis() - countdownStart) / 1000);
      
      if (remain <= 0) {
        promptMsg = "ACCESS GRANTED!"; 
        game_log = "ALL STAGES CLEARED";
        kilitServo.write(0); // UNLOCK!
        deviceMode = "UNLOCKED";
        currentStage = 4;
      } else {
        promptMsg = "HOLD... " + String(remain);
      }
    } else {
      if (countdownStart != 0) { 
        countdownStart = 0; triggerVib(400); promptMsg = "SYNC LOST! RETRY";
      } else {
        promptMsg = "TASK: SYNC SENSORS";
      }
    }
  }
}

// ==========================================
// 3. CLOUD COMMANDS CALLBACK (HACKER)
// ==========================================
void onHackerCmdChange() {
  if (hacker_cmd == "STAGE1") {
    currentStage = 1; passIndex = 0; deviceMode = "STAGE 1";
    targetPass[0] = (int)temp / 10;
    targetPass[1] = (int)temp % 10;
    targetPass[2] = (targetPass[0] + targetPass[1]) % 10;
    promptMsg = "TASK: ENTER CODE";
    game_log = "CODE GENERATED: " + String(targetPass[0]) + String(targetPass[1]) + String(targetPass[2]);
  }
  else if (hacker_cmd == "STAGE2") {
    currentStage = 2; mazeX = 2; mazeY = 4; mazeReady = false; 
    deviceMode = "STAGE 2";
    promptMsg = "TASK: NAVIGATE";
    game_log = "MAZE INITIATED";
  }
  else if (hacker_cmd == "STAGE3") {
    currentStage = 3; countdownStart = 0; deviceMode = "STAGE 3";
    promptMsg = "TASK: SYNC SENSORS";
  }
  else if (hacker_cmd == "OPEN") {
    kilitServo.write(0); promptMsg = "FORCE OPENED"; deviceMode = "UNLOCKED";
  }
  else if (hacker_cmd == "CLOSE") {
    kilitServo.write(40); promptMsg = "LOCKED"; deviceMode = "LOCKED"; currentStage = 0;
  }
  else if (hacker_cmd.startsWith("VIB")) {
    if (hacker_cmd == "VIBLONG") {
      triggerVib(1200); 
    } 
    else if (hacker_cmd.length() > 3) {
      int count = hacker_cmd.substring(3).toInt(); 
      if (count > 0 && count <= 9) {
        for(int i = 0; i < count; i++) {
          triggerVib(400); 
          delay(400);      
        }
      }
    } 
    else {
      triggerVib(400);
    }
  }
}

void triggerVib(int duration) {
  digitalWrite(VIB_PIN, HIGH);
  delay(duration);
  digitalWrite(VIB_PIN, LOW);
}

// ==========================================
// 4. OLED UI RENDER
// ==========================================
void updateUI() {
  display.clearDisplay(); display.setTextColor(WHITE);

  // ZONE 1: Status Bar
  display.drawRect(0, 0, 128, 14, WHITE);
  display.setCursor(2, 4); display.setTextSize(1);
  display.print("RSSI:"); display.print(WiFi.RSSI());
  display.setCursor(82, 4); 
  display.print(ArduinoCloud.connected() ? "CLOUD:OK" : "NO CLOUD");

  // ZONE 2: Sensors & Mode 
  display.setCursor(2, 18); display.print("MODE: "); display.print(deviceMode);
  display.setCursor(2, 28); display.print("DIST: "); display.print(dist); display.print("cm");
  display.setCursor(2, 38); display.print("TEMP: "); display.print(temp, 1); display.print("C");
  display.setCursor(68, 28); display.print("DIAL:"); display.print(dial);
  display.setCursor(68, 38); display.print("LDR :"); display.print(light);

  // ZONE 3: Prompt Zone
  display.drawFastHLine(0, 50, 128, WHITE);
  display.setCursor(2, 54); display.print("> "); display.print(promptMsg);

  display.display();
}

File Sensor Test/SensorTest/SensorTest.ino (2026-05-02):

#include <Wire.h>
#include <Adafruit_GFX.h>
#include <Adafruit_SSD1306.h>
#include <Adafruit_MPU6050.h>
#include <Adafruit_Sensor.h>
#include <DHT.h>
#include <ESP32Servo.h>

// --- PİN TANIMLAMALARI (Seninle konuştuğumuz şemaya göre) ---
#define OLED_RESET     -1
#define SCREEN_WIDTH   128
#define SCREEN_HEIGHT  64
Adafruit_SSD1306 display(SCREEN_WIDTH, SCREEN_HEIGHT, &Wire, OLED_RESET);

Adafruit_MPU6050 mpu;

#define DHTPIN         4
#define DHTTYPE        DHT11
DHT dht(DHTPIN, DHTTYPE);

#define ENC_CLK        32
#define ENC_DT         33
#define ENC_SW         25

#define ULTRA_TRIG     5
#define ULTRA_ECHO     18

#define LDR_PIN        34

#define SERVO_PIN      26
Servo myservo;

#define VIB_PIN        27

// --- DEĞİŞKENLER ---
int lastClk = HIGH;
int encoderCount = 0;

void setup() {
  Serial.begin(115200);
  while (!Serial);
  Serial.println("OmniDeck Sistem Testi Basliyor...");

  // 1. OLED Başlatma
  if(!display.begin(SSD1306_SWITCHCAPVCC, 0x3C)) {
    Serial.println("OLED Hatasi!");
  }
  display.clearDisplay();
  display.setTextSize(1);
  display.setTextColor(WHITE);
  display.setCursor(0,0);
  display.println("OMNIDECK TEST");
  display.display();
  delay(1000);

  // 2. MPU6050 Başlatma
  if (!mpu.begin()) {
    Serial.println("MPU6050 bulunamadi!");
  }
  mpu.setAccelerometerRange(MPU6050_RANGE_8_G);

  // 3. DHT11 Başlatma
  dht.begin();

  // 4. Pin Modları
  pinMode(ENC_CLK, INPUT_PULLUP);
  pinMode(ENC_DT, INPUT_PULLUP);
  pinMode(ENC_SW, INPUT_PULLUP);
  pinMode(ULTRA_TRIG, OUTPUT);
  pinMode(ULTRA_ECHO, INPUT);
  pinMode(VIB_PIN, OUTPUT);

  // 5. Servo Başlatma
  ESP32PWM::allocateTimer(0);
  myservo.setPeriodHertz(50);
  myservo.attach(SERVO_PIN, 500, 2400);
  
  Serial.println("Sistem Hazir!");
}

void loop() {
  display.clearDisplay();
  display.setCursor(0,0);

  // --- 1. MPU6050 TEST (Eğme) ---
  sensors_event_t a, g, temp;
  mpu.getEvent(&a, &g, &temp);
  display.print("MPU X:"); display.print(a.acceleration.x, 1);
  display.print(" Y:"); display.println(a.acceleration.y, 1);

  // --- 2. DHT11 TEST (Isı/Nem) ---
  float h = dht.readHumidity();
  float t = dht.readTemperature();
  display.print("Temp:"); display.print(t, 1);
  display.print("C Hum:%"); display.println(h, 0);

  // --- 3. LDR TEST (Işık) ---
  int ldrVal = analogRead(LDR_PIN);
  display.print("Iisik:"); display.println(ldrVal);

  // --- 4. ULTRASONIK TEST (Mesafe) ---
  digitalWrite(ULTRA_TRIG, LOW);
  delayMicroseconds(2);
  digitalWrite(ULTRA_TRIG, HIGH);
  delayMicroseconds(10);
  digitalWrite(ULTRA_TRIG, LOW);
  long duration = pulseIn(ULTRA_ECHO, HIGH);
  float distance = duration * 0.034 / 2;
  display.print("Mesafe:"); display.print(distance, 1); display.println(" cm");

  // --- 5. ENCODER TEST (Düğme) ---
  int newClk = digitalRead(ENC_CLK);
  if (newClk != lastClk && newClk == LOW) {
    if (digitalRead(ENC_DT) != newClk) encoderCount++;
    else encoderCount--;
  }
  lastClk = newClk;
  display.print("Enc:"); display.print(encoderCount);
  if(digitalRead(ENC_SW) == LOW) display.print(" [BASILDI]");
  display.println();

  // --- 6. ACTUATOR TEST (Servo ve Motor) ---
  
  // Işık testi (LDR) - Karanlıksa titret
  if(ldrVal < 500) {
    digitalWrite(VIB_PIN, HIGH);
    display.println("!!! TITRESIM AKTIF !!!");
  } else {
    digitalWrite(VIB_PIN, LOW);
  }

  if(distance < 10) {
    // TETIKLEME ANI: Kilit açılıyor
    // 40'tan 0'a gitmek saat yönünde harekettir.
    myservo.write(0); 
    display.println(">>> KILIT ACIK (0 deg) <<<");
  } else {
    // BEKLEME ANI: Kilit pozisyonu (Kilitli tutmak için 40 dereceye geri döner)
    myservo.write(40); 
    display.println("--- KILITLI (40 deg) ---");
  }
  display.display();
  delay(100); // Ekran tazeleme hızı
}

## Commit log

2026-04-29 3D model for the device finished
    [3DLid.3mf, 3DLid.scad, 3DShell.scad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]
2026-04-29 3d model assembly
2026-05-02 Prototype Finished and usable via Ardunio Dashboard
    [3DShellandLid.3mf, Lid.3mf, Lid.scad]
2026-05-02 OmniDeck Wiring
2026-05-02 Revise README for clarity and detail enhancement
    Updated project description and added components list with wiring details. Revised core concept and included cloud setup instructions.
